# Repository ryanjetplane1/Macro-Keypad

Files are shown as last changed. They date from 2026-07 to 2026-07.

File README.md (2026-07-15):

# Macropad

A wireless BLE keyboard the size of your hand for custom hotkeys.
thumbnail (1)

This project was made for Hack Club as an affordable alternative to commercial Macropads. The Macropad uses the ESP32 core chip for latency-free Bluetooth transmission, taking sub 50ms. Features include key debouncing, a status LED indicator, a quick swap keybind changing tool, and an internal memory storage bank. Menu choices and key layouts can be configured easily using the desktop app.

## BOM

| Component | Description | Quantity | Approx Price (USD) |
| :--- | :--- | :--- | :--- |
| **ESP32 Dev Kit** | Microcontroller | 1 | $4.50 |
| **Tactile Buttons** | Tap input keys (any brand cherry mx style) | 3 | $0.30 |
| **Status LED** | Indication led for network states | 1 | $0.10 |
| **FR1 Copper Clad Sheet** | Base board for pcb | 1 | $1.00 |
| **Total Cost** | -- | -- | **~$5.90** |

---

## How it works

### 1. Keyboard Firmware
The ESP32 mimics a standard Bluetooth keyboard so your computer recognizes and trusts it. At the same time, it leaves a connection open for your Windows application to connect. This lets you rebind your gaming keys instantly without losing connection. Once sent, the new keys save directly to the onboard memory so they stick even after a reboot.

### 2. Desktop Firmware
Windows recognizes the Macropad as a standard USB device when it is plugged in. The desktop app connects directly to this active USB port and listens for the hardware footprint. Once selected, it streams your new keybind configuration data through the cable.

---
## Wiring Guide

```text
Button Wiring:
* Button 1       | GPIO 0 | GND
* Button 2       | GPIO 1 | GND
* Button 3       | GPIO 2 | GND

Battery Wiring:
* Battery (+)    | TP4056 (B+)
* Battery (-)    | TP4056 (B-)
* TP4056 (OUT-)  | ESP32 (GND)
* TP4056 (OUT+)  | Switch (Middle Pin)
* Switch (Outer) | ESP32 (VIN / 5V)

LED Wiring:
* Long Leg (+)   | ESP32 (GPIO 4)
* Short Leg (-)  | ESP32 (GND)
```

## Building & Compiling

### Arduino Firmware Setup
Ensure you have the `NimBLE-Arduino` package installed through your library manager. Compile and flash the script directly to your ESP32 board.

### Native Windows App Compilation
If you make modifications to the Python app script, re-bundle the project into an `.exe` using the system tool command:

```powershell
# Setup requirements
pip install bleak customtkinter pyinstaller

# Build into a executable
python -m PyInstaller --noconsole --onefile keybinds.py
```
Your compiled launcher will be placed cleanly inside the newly generated `/dist` directory.

### Final look


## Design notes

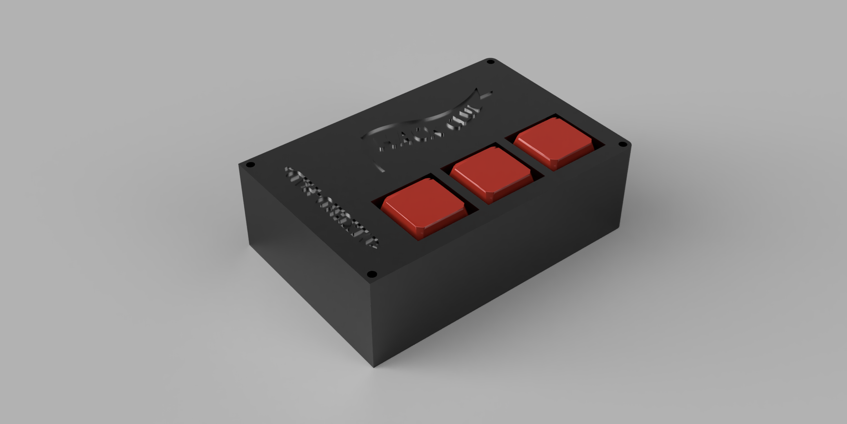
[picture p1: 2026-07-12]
thumbnail.png

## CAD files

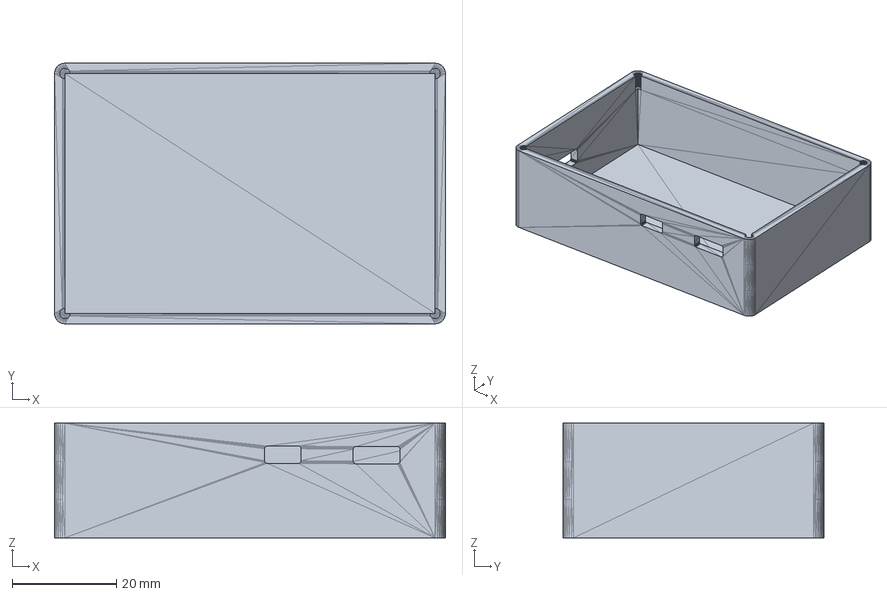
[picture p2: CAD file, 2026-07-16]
cad/hackpadbottom.step
75.0 x 50.0 x 22.0 mm

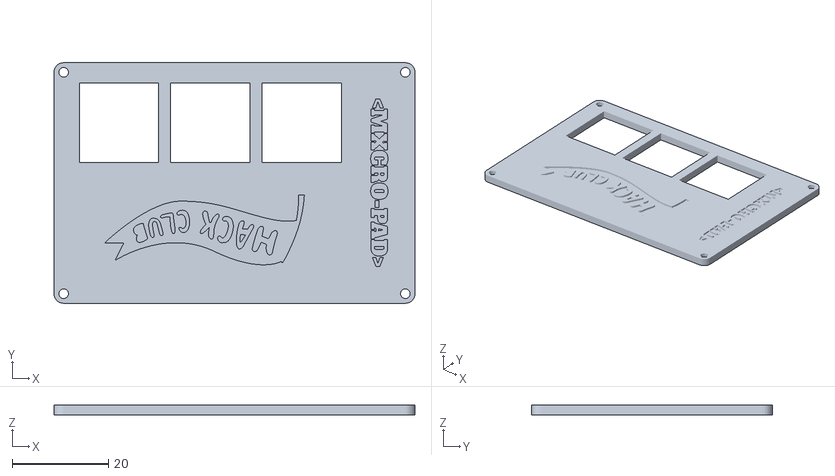
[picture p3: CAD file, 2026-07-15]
cad/hackpadtop.stl
75.0 x 50.0 x 2.00

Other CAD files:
cad/hackpadbottom.stl

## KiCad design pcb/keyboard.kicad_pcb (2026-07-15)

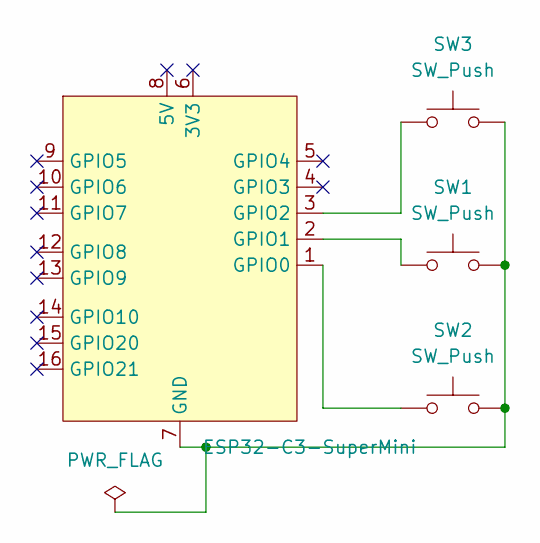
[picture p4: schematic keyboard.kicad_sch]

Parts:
SW1, SW2, SW3: SW_Push; MX-Solderable-1U
U1: ESP32-C3-SuperMini

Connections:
unnamed: SW1.2, SW2.2, SW3.2, U1.7 (GND)
unnamed: SW2.1, U1.1 (GPIO0)
unnamed: SW1.1, U1.2 (GPIO1)
unnamed: SW3.1, U1.3 (GPIO2)

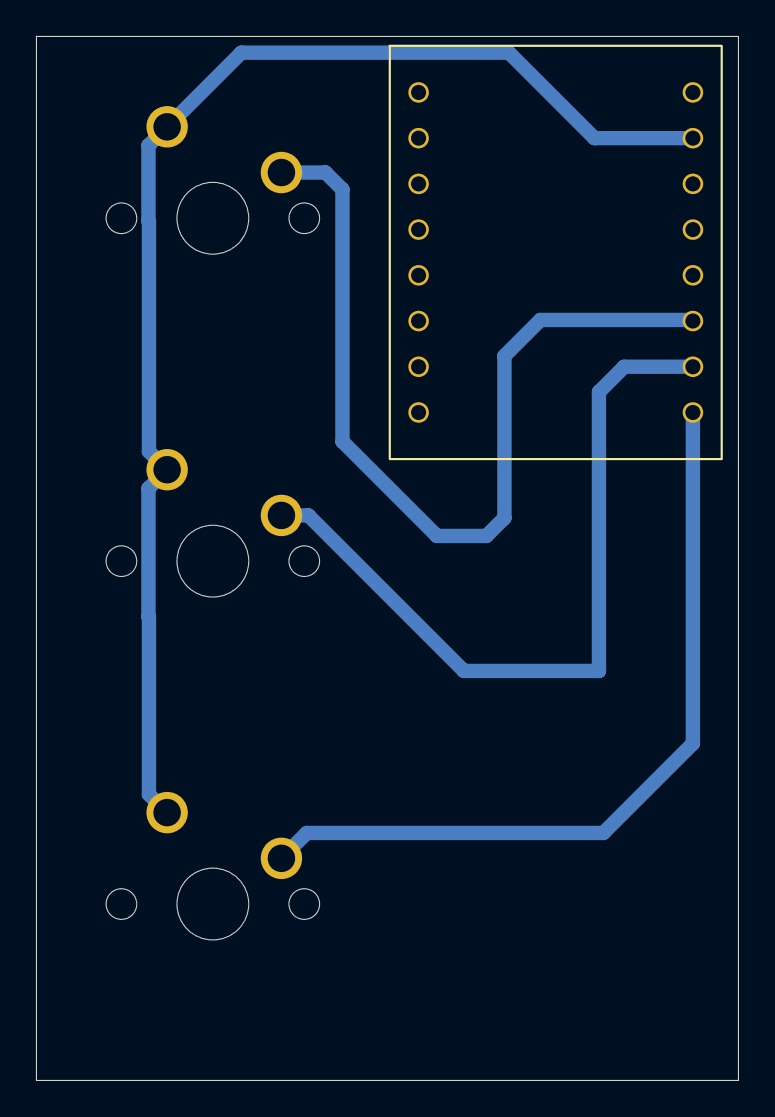
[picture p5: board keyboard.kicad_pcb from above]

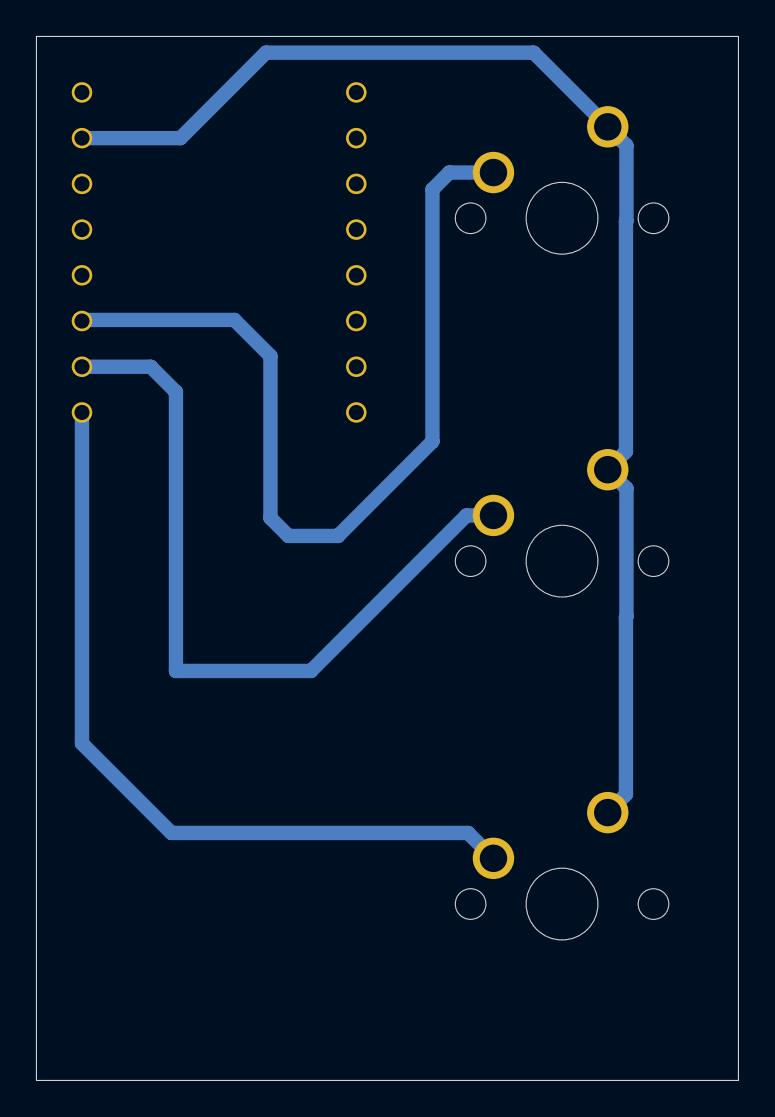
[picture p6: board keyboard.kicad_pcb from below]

Board: 2 copper layers, 39.0 x 58.0 mm, 4 parts (3 on the bottom side), 4 nets.

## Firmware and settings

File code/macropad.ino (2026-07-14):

#include <HijelHID_BLEKeyboard.h>
#include <Preferences.h>
#include <NimBLEDevice.h>

#define CONFIG_SERVICE_UUID        "a1b2c3d0-0001-0001-0001-000000000001"
#define KEYMAP_WRITE_CHAR_UUID     "a1b2c3d0-0001-0001-0001-000000000002"
#define KEYMAP_READ_CHAR_UUID      "a1b2c3d0-0001-0001-0001-000000000003"

HijelHID_BLEKeyboard keyboard("Macropad", "Espressif", 100);
Preferences prefs;

const int PIN_1 = 0;
const int PIN_2 = 1;
const int PIN_3 = 2;
const int STATUS_LED_PIN = 4;

int lastState1 = HIGH;
int lastState2 = HIGH;
int lastState3 = HIGH;

unsigned long lastDebounceTime1 = 0;
unsigned long lastDebounceTime2 = 0;
unsigned long lastDebounceTime3 = 0;
const unsigned long DEBOUNCE_DELAY = 15;

unsigned long lastLedToggleTime = 0;
const unsigned long BLINK_INTERVAL = 500;
int ledState = LOW;

uint16_t keymap[3] = { KEY_F, KEY_G, KEY_F6 };

NimBLECharacteristic *keymapWriteChar;
NimBLECharacteristic *keymapReadChar;

void onPairingCompleteHandler(bool success) {
  if (success) {
    Serial.println("[APP] Pairing succeeded, restarting advertising to allow another connection");
    NimBLEDevice::startAdvertising();
  } else {
    Serial.println("[APP] Pairing failed");
  }
}

String serialBuffer = "";

void sendKey(uint16_t keycode) {
  uint8_t mod = (keycode >> 8) & 0xFF;
  uint8_t key = keycode & 0xFF;
  
  if (mod == 0) {
    keyboard.tap(key);
  } else {
    // Cast explicitly to uint8_t to resolve ambiguous overload
    if (mod & 0x01) keyboard.press((uint8_t)0xE0);
    if (mod & 0x02) keyboard.press((uint8_t)0xE1);
    if (mod & 0x04) keyboard.press((uint8_t)0xE2);
    if (mod & 0x08) keyboard.press((uint8_t)0xE3);
    
    if (key != 0) {
      keyboard.press(key);
    }
    
    delay(15);
    keyboard.releaseAll();
  }
}

void handleSerialCommand(String cmd) {
  cmd.trim();
  if (cmd.startsWith("SET ")) {
    int firstSpace = cmd.indexOf(' ');
    int secondSpace = cmd.indexOf(' ', firstSpace + 1);
    if (secondSpace == -1) {
      Serial.println("ERR malformed SET command");
      return;
    }
    String indexStr = cmd.substring(firstSpace + 1, secondSpace);
    String keyStr = cmd.substring(secondSpace + 1);
    int index = indexStr.toInt();
    if (index < 0 || index > 2) {
      Serial.println("ERR index out of range");
      return;
    }
    
    uint16_t keyCode = (uint16_t)strtol(keyStr.c_str(), nullptr, 16);
    keymap[index] = keyCode;
    saveKeymapIndex(index);
    updateReadCharacteristic();
    Serial.printf("OK %d %04X\n", index, keyCode);
  } else if (cmd == "GET") {
    Serial.printf("MAP %04X %04X %04X\n", keymap[0], keymap[1], keymap[2]);
  } else if (cmd.length() > 0) {
    Serial.println("ERR unknown command");
  }
}

void processSerialCommands() {
  while (Serial.available() > 0) {
    char c = Serial.read();
    if (c == '\n') {
      handleSerialCommand(serialBuffer);
      serialBuffer = "";
    } else if (c != '\r') {
      serialBuffer += c;
    }
  }
}

void loadKeymap() {
  prefs.begin("macropad", true);
  keymap[0] = prefs.getUShort("key0", KEY_F);
  keymap[1] = prefs.getUShort("key1", KEY_G);
  keymap[2] = prefs.getUShort("key2", KEY_F6);
  prefs.end();
  Serial.printf("[BOOT] Loaded keymap: %04X %04X %04X\n", keymap[0], keymap[1], keymap[2]);
}

void saveKeymapIndex(uint8_t index) {
  prefs.begin("macropad", false);
  char key[8];
  snprintf(key, sizeof(key), "key%d", index);
  prefs.putUShort(key, keymap[index]);
  prefs.end();
  Serial.printf("[PREFS] Saved key%d = %04X\n", index, keymap[index]);
}

void updateReadCharacteristic() {
  uint16_t payload[3] = { keymap[0], keymap[1], keymap[2] };
  keymapReadChar->setValue((uint8_t*)payload, 6);
  Serial.printf("[CHAR] Read characteristic updated: %04X %04X %04X\n", payload[0], payload[1], payload[2]);
}

class KeymapWriteCallbacks : public NimBLECharacteristicCallbacks {
  void onWrite(NimBLECharacteristic *pChar) {
    std::string value = pChar->getValue();
    Serial.printf("[WRITE] Received %d bytes\n", (int)value.length());
    
    if (value.length() == 3) {
      uint8_t index = (uint8_t)value[0];
      uint16_t keyCode = (uint8_t)value[1] | ((uint16_t)value[2] << 8);
      Serial.printf("[WRITE] index=%d keyCode=%04X\n", index, keyCode);
      
      if (index > 2) {
        Serial.println("[WRITE] Rejected: index out of range");
        return;
      }
      keymap[index] = keyCode;
      saveKeymapIndex(index);
      updateReadCharacteristic();
    } else {
      Serial.println("[WRITE] Rejected: wrong payload length");
    }
  }

  void onSubscribe(NimBLECharacteristic *pChar, ble_gap_conn_desc *desc, uint16_t subValue) {
    Serial.printf("[SUB] Client subscribe state changed: %d\n", subValue);
  }
};

void setupConfigService() {
  Serial.println("[SETUP] Getting NimBLE server instance");
  NimBLEServer *server = keyboard.getServer();
  Serial.printf("[SETUP] Server pointer: %p\n", server);

  NimBLEService *configService = server->createService(CONFIG_SERVICE_UUID);
  Serial.println("[SETUP] Config service created");

  keymapWriteChar = configService->createCharacteristic(
    KEYMAP_WRITE_CHAR_UUID,
    NIMBLE_PROPERTY::WRITE
  );
  keymapWriteChar->setCallbacks(new KeymapWriteCallbacks());
  Serial.println("[SETUP] Write characteristic created");

  keymapReadChar = configService->createCharacteristic(
    KEYMAP_READ_CHAR_UUID,
    NIMBLE_PROPERTY::READ | NIMBLE_PROPERTY::NOTIFY
  );
  updateReadCharacteristic();
  Serial.println("[SETUP] Read characteristic created");

  configService->start();
  Serial.println("[SETUP] Config service started");

  NimBLEAdvertising *advertising = NimBLEDevice::getAdvertising();
  advertising->stop();
  delay(50);
  advertising->start();
  Serial.println("[SETUP] Advertising restarted with config service active");
}

void setup() {
  Serial.begin(115200);
  delay(500);
  Serial.println("[BOOT] Starting up");

  pinMode(PIN_1, INPUT_PULLUP);
  pinMode(PIN_2, INPUT_PULLUP);
  pinMode(PIN_3, INPUT_PULLUP);
  pinMode(STATUS_LED_PIN, OUTPUT);
  digitalWrite(STATUS_LED_PIN, ledState);

  delay(2000);

  loadKeymap();

  keyboard.setLogLevel(HIDLogLevel::Verbose);
  keyboard.onPairingComplete(onPairingCompleteHandler);

  Serial.println("[BOOT] Calling keyboard.begin()");
  keyboard.begin();
  Serial.println("[BOOT] keyboard.begin() returned");

  setupConfigService();

  Serial.println("[BOOT] Setup complete, entering loop");
}

void loop() {
  unsigned long currentMillis = millis();

  static bool wasPaired = false;
  bool isPaired = keyboard.isPaired();
  if (isPaired != wasPaired) {
    Serial.printf("[BLE] Pairing state changed: %s\n", isPaired ? "PAIRED" : "NOT PAIRED");
    wasPaired = isPaired;
  }

  if (isPaired) {
    ledState = HIGH;
    digitalWrite(STATUS_LED_PIN, ledState);
  } else {
    if (currentMillis - lastLedToggleTime >= BLINK_INTERVAL) {
      lastLedToggleTime = currentMillis;
      ledState = !ledState;
      digitalWrite(STATUS_LED_PIN, ledState);
    }
  }

  int reading1 = digitalRead(PIN_1);
  if (reading1 != lastState1) {
    if ((currentMillis - lastDebounceTime1) > DEBOUNCE_DELAY) {
      if (reading1 == LOW && isPaired) {
        Serial.printf("[BTN] Button 1 -> keycode %04X\n", keymap[0]);
        sendKey(keymap[0]);
      }
      lastState1 = reading1;
      lastDebounceTime1 = currentMillis;
    }
  }

  int reading2 = digitalRead(PIN_2);
  if (reading2 != lastState2) {
    if ((currentMillis - lastDebounceTime2) > DEBOUNCE_DELAY) {
      if (reading2 == LOW && isPaired) {
        Serial.printf("[BTN] Button 2 -> keycode %04X\n", keymap[1]);
        sendKey(keymap[1]);
      }
      lastState2 = reading2;
      lastDebounceTime2 = currentMillis;
    }
  }

  int reading3 = digitalRead(PIN_3);
  if (reading3 != lastState3) {
    if ((currentMillis - lastDebounceTime3) > DEBOUNCE_DELAY) {
      if (reading3 == LOW && isPaired) {
        Serial.printf("[BTN] Button 3 -> keycode %04X\n", keymap[2]);
        sendKey(keymap[2]);
      }
      lastState3 = reading3;
      lastDebounceTime3 = currentMillis;
    }
  }

  processSerialCommands();

  delay(5);
}

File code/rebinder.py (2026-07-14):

import threading
import queue
import customtkinter as ctk
import serial
import serial.tools.list_ports

KEYS = {
    "F1": 0x3A, "F2": 0x3B, "F3": 0x3C, "F4": 0x3D, "F5": 0x3E, "F6": 0x3F,
    "F7": 0x40, "F8": 0x41, "F9": 0x42, "F10": 0x43, "F11": 0x44, "F12": 0x45,
    "ESCAPE": 0x29, "RETURN": 0x28, "TAB": 0x2B, "BACKSPACE": 0x2A,
    "DELETE": 0x4C, "INSERT": 0x49, "HOME": 0x4A, "END": 0x4D,
    "PAGE_UP": 0x4B, "PAGE_DOWN": 0x4E, "CAPS_LOCK": 0x39,
    "UP": 0x52, "DOWN": 0x51, "LEFT": 0x50, "RIGHT": 0x4F,
    "LEFT_CTRL": 0xE0, "LEFT_SHIFT": 0xE1, "LEFT_ALT": 0xE2, "LEFT_GUI": 0xE3,
    "RIGHT_CTRL": 0xE4, "RIGHT_SHIFT": 0xE5, "RIGHT_ALT": 0xE6, "RIGHT_GUI": 0xE7,
    "SPACE": 0x2C, "MINUS": 0x2D, "EQUAL": 0x2E, "LEFTBRACE": 0x2F,
    "RIGHTBRACE": 0x30, "BACKSLASH": 0x31, "SEMICOLON": 0x33,
    "APOSTROPHE": 0x34, "GRAVE": 0x35, "COMMA": 0x36, "DOT": 0x37, "SLASH": 0x38,
}

CHARS = {
    ' ': "SPACE", '-': "MINUS", '=': "EQUAL", '[': "LEFTBRACE",
    ']': "RIGHTBRACE", '\\': "BACKSLASH", ';': "SEMICOLON",
    "'": "APOSTROPHE", '`': "GRAVE", ',': "COMMA", '.': "DOT", '/': "SLASH"
}

LETS = {chr(ord('a') + i): 0x04 + i for i in range(26)}
DIGS = {
    "1": 0x1E, "2": 0x1F, "3": 0x20, "4": 0x21, "5": 0x22,
    "6": 0x23, "7": 0x24, "8": 0x25, "9": 0x26, "0": 0x27,
}

TKS = {
    "Escape": "ESCAPE", "Return": "RETURN", "Tab": "TAB", "BackSpace": "BACKSPACE",
    "Delete": "DELETE", "Insert": "INSERT", "Home": "HOME", "End": "END",
    "Prior": "PAGE_UP", "Next": "PAGE_DOWN", "Caps_Lock": "CAPS_LOCK",
    "Up": "UP", "Down": "DOWN", "Left": "LEFT", "Right": "RIGHT",
    "Control_L": "LEFT_CTRL", "Shift_L": "LEFT_SHIFT", "Alt_L": "LEFT_ALT",
    "Control_R": "RIGHT_CTRL", "Shift_R": "RIGHT_SHIFT", "Alt_R": "RIGHT_ALT",
    "F1": "F1", "F2": "F2", "F3": "F3", "F4": "F4", "F5": "F5", "F6": "F6",
    "F7": "F7", "F8": "F8", "F9": "F9", "F10": "F10", "F11": "F11", "F12": "F12",
}

def get_kc(sym, ch):
    s_l = sym.lower() if sym else ""
    
    if sym in TKS: return KEYS[TKS[sym]], TKS[sym]
    
    TKS_P = {
        "space": "SPACE", "minus": "MINUS", "equal": "EQUAL", "bracketleft": "LEFTBRACE",
        "bracketright": "RIGHTBRACE", "backslash": "BACKSLASH", "semicolon": "SEMICOLON",
        "apostrophe": "APOSTROPHE", "quoteright": "APOSTROPHE", "grave": "GRAVE",
        "quoteleft": "GRAVE", "comma": "COMMA", "period": "DOT", "slash": "SLASH"
    }
    if s_l in TKS_P: return KEYS[TKS_P[s_l]], TKS_P[s_l]
    if s_l in LETS: return LETS[s_l], s_l.upper()
    if sym in DIGS: return DIGS[sym], sym
    
    SH_S = {
        'exclam': '1', 'at': '2', 'numbersign': '3', 'dollar': '4', 'percent': '5',
        'asciicircum': '6', 'ampersand': '7', 'asterisk': '8', 'parenleft': '9',
        'parenright': '0', 'asciitilde': 'grave', 'underscore': 'minus', 'plus': 'equal',
        'braceleft': 'bracketleft', 'braceright': 'bracketright', 'bar': 'backslash',
        'colon': 'semicolon', 'quotedbl': 'apostrophe', 'less': 'comma',
        'greater': 'period', 'question': 'slash'
    }
    if s_l in SH_S:
        b = SH_S[s_l]
        if b in DIGS: return DIGS[b], b
        if b in TKS_P: return KEYS[TKS_P[b]], TKS_P[b]

    if ch in CHARS: return KEYS[CHARS[ch]], CHARS[ch]
    return None, None

def get_lbl(c):
    if c is None: return "—"
    mods = (c >> 8) & 0xFF
    kc = c & 0xFF
    
    lbls = []
    if mods & 0x01: lbls.append("CTRL")
    if mods & 0x02: lbls.append("SHIFT")
    if mods & 0x04: lbls.append("ALT")
    if mods & 0x08: lbls.append("GUI")
    
    base = "Unk"
    for n, v in KEYS.items():
        if v == kc: base = n; break
    if base == "Unk":
        for ch, v in LETS.items():
            if v == kc: base = ch.upper(); break
    if base == "Unk":
        for ch, v in DIGS.items():
            if v == kc: base = ch; break
    if base == "Unk" and kc != 0:
        base = f"0x{kc:02X}"
    elif base == "Unk":
        base = ""
        
    if mods and base:
        return "+".join(lbls) + "+" + base
    elif mods:
        return "+".join(lbls)
    elif base:
        return base
    return "—"

class SerWrk:
    def __init__(self, q):
        self.q = q
        self.s = None
        self.th = None
        self.stp = threading.Event()
        self.poll_th = threading.Thread(target=self._poll_ports, daemon=True)
        self.poll_th.start()

    def _poll_ports(self):
        import time
        last_ports = []
        while True:
            try:
                pts = self.prts()
                if pts != last_ports:
                    last_ports = pts
                    self.q.put(("ports", pts))
            except Exception:
                pass
            time.sleep(0.5)

    @staticmethod
    def prts():
        return [p.device for p in serial.tools.list_ports.comports()]

    def con(self, p):
        threading.Thread(target=self.c_wk, args=(p,), daemon=True).start()

    def c_wk(self, p):
        self.dcon()  # Ensure any existing connection is cleanly shut down first
        
        try:
            # Use a small timeout so closing the port doesn't block
            new_s = serial.Serial(p, baudrate=115200, timeout=0.05)
        except Exception as e:
            self.q.put(("st", f"ERR: {e}"))
            return

        self.s = new_s
        self.q.put(("st", "Connected"))
        self.stp.clear()
        
        # Pass the specific new_s object into the thread to isolate reads safely
        self.th = threading.Thread(target=self.r_lp, args=(new_s,), daemon=True)
        self.th.start()
        self.q_map()

    def r_lp(self, current_s):
        # We exclusively interact with `current_s` here instead of `self.s`
        buf = b""
        while not self.stp.is_set() and current_s.is_open:
            try:
                # Read max available bytes, or wait up to 0.05s
                r = current_s.read(max(1, current_s.in_waiting))
                if r:
                    buf += r
                    while b'\n' in buf:
                        line, buf = buf.split(b'\n', 1)
                        l = line.decode(errors="ignore").strip()
                        if l:
                            self.h_ln(l)
            except Exception:
                break # Exception happens if disconnected physically or via dcon() closing the port

    def h_ln(self, l):
        pts = l.split()
        if l.startswith("MAP ") and len(pts) == 4:
            try:
                self.q.put(("map", [int(pts[i], 16) for i in range(1, 4)]))
            except ValueError:
                pass
        elif l.startswith("OK ") and len(pts) == 3:
            try:
                self.q.put(("ack", int(pts[1])))
            except ValueError:
                pass
            self.q_map()
        elif l.startswith("ERR"):
            self.q.put(("st", f"ERR: {l}"))
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
